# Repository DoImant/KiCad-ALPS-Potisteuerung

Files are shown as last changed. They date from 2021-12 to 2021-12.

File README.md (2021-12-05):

# ALPS potentiometer control

Circuit for controlling an ALPS motor potentiometer with the help of an IR remote\
control. This circuit can be used to control the volume of an amplifier.

## Circuit diagram as PDF file

[Sheet](https://github.com/DoImant/Stuff/blob/main/ALPS-Drehpoti/ALPS-Potisteuerung.pdf)

## The PCB

PCB



## Software

The software for the Atmega88P can be found here: https://github.com/DoImant/ATmega88-ALPS-Motorpoti

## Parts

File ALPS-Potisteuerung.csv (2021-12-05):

Reference | Quantity | Value | Footprint | Datasheet | EAN / GTIN | Hersteller | Distributor | Artikelnummer Distributor
C1 | 1 | 220u | Capacitor_SMD:CP_Elec_6.3x5.8 | ~ | 9900002001580 | Panasonic | Reichelt | EEEFT1C221AP
C2 C3 | 2 | 1uF | Capacitor_SMD:C_1206_3216Metric_Pad1.33x1.80mm_HandSolder | ~
C4 C5 C9 C10 | 4 | 100n | Capacitor_SMD:C_1206_3216Metric_Pad1.33x1.80mm_HandSolder | ~
C6 C7 | 2 | 22p | Capacitor_THT:C_Disc_D3.0mm_W1.6mm_P2.50mm | ~
C8 | 1 | 10n | Capacitor_SMD:C_1206_3216Metric_Pad1.33x1.80mm_HandSolder | ~
D1 | 1 | MBR0520LT | Diode_SMD:D_SOD-123 | http://www.onsemi.com/pub_link/Collateral/MBR0520LT1-D.PDF | 9900002196200 | ON Semiconductor | Reichelt
H1 H2 H3 H4 | 4 | MountingHole | MountingHole:MountingHole_3.2mm_M3_DIN965_Pad | ~
J1 | 1 | Conn_01x02 | TerminalBlock_RND:TerminalBlock_RND_205-00232_1x02_P5.08mm_Horizontal | ~
J2 | 1 | Conn_01x03_Male | Connector_JST:JST_XH_B3B-XH-A_1x03_P2.50mm_Vertical | ~
J3 | 1 | Conn_02x03_Odd_Even | Connector_IDC:IDC-Header_2x03_P2.54mm_Vertical | ~
J4 | 1 | Conn_01x02 | Connector_PinHeader_2.54mm:PinHeader_1x02_P2.54mm_Vertical | ~
J5 | 1 | Conn_01x02 | Connector_JST:JST_XH_B2B-XH-A_1x02_P2.50mm_Vertical | ~
Q1 | 1 | IRLML6402 | Package_TO_SOT_SMD:SOT-23 | https://www.infineon.com/dgdl/irlml6402pbf.pdf?fileId=5546d462533600a401535668d5c2263c | 9900001087431 | Infenion | Reichelt
R1 | 1 | 22k | Resistor_SMD:R_1206_3216Metric_Pad1.30x1.75mm_HandSolder | ~
R2 | 1 | 150 | Resistor_SMD:R_1206_3216Metric_Pad1.30x1.75mm_HandSolder | ~
R3 | 1 | 56k | Resistor_SMD:R_1206_3216Metric_Pad1.30x1.75mm_HandSolder | ~
U1 | 1 | MCP1703A-5002_SOT23 | Package_TO_SOT_SMD:SOT-23 | http://ww1.microchip.com/downloads/en/DeviceDoc/20005122B.pdf | 9900001372926 | Microchip | Reichelt
U2 | 1 | ATmega88PA-PU | Package_DIP:DIP-28_W7.62mm | http://ww1.microchip.com/downloads/en/DeviceDoc/ATmega48PA_88PA_168PA-Data-Sheet-40002011A.pdf | 9900001218354 | Microchip | Reichelt
U3 | 1 | L293D | Package_DIP:DIP-16_W7.62mm | http://www.ti.com/lit/ds/symlink/l293.pdf | 9900000096618 | ST Microeletronics
Y1 | 1 | 8Mhz | Crystal:Crystal_HC49-4H_Vertical | ~

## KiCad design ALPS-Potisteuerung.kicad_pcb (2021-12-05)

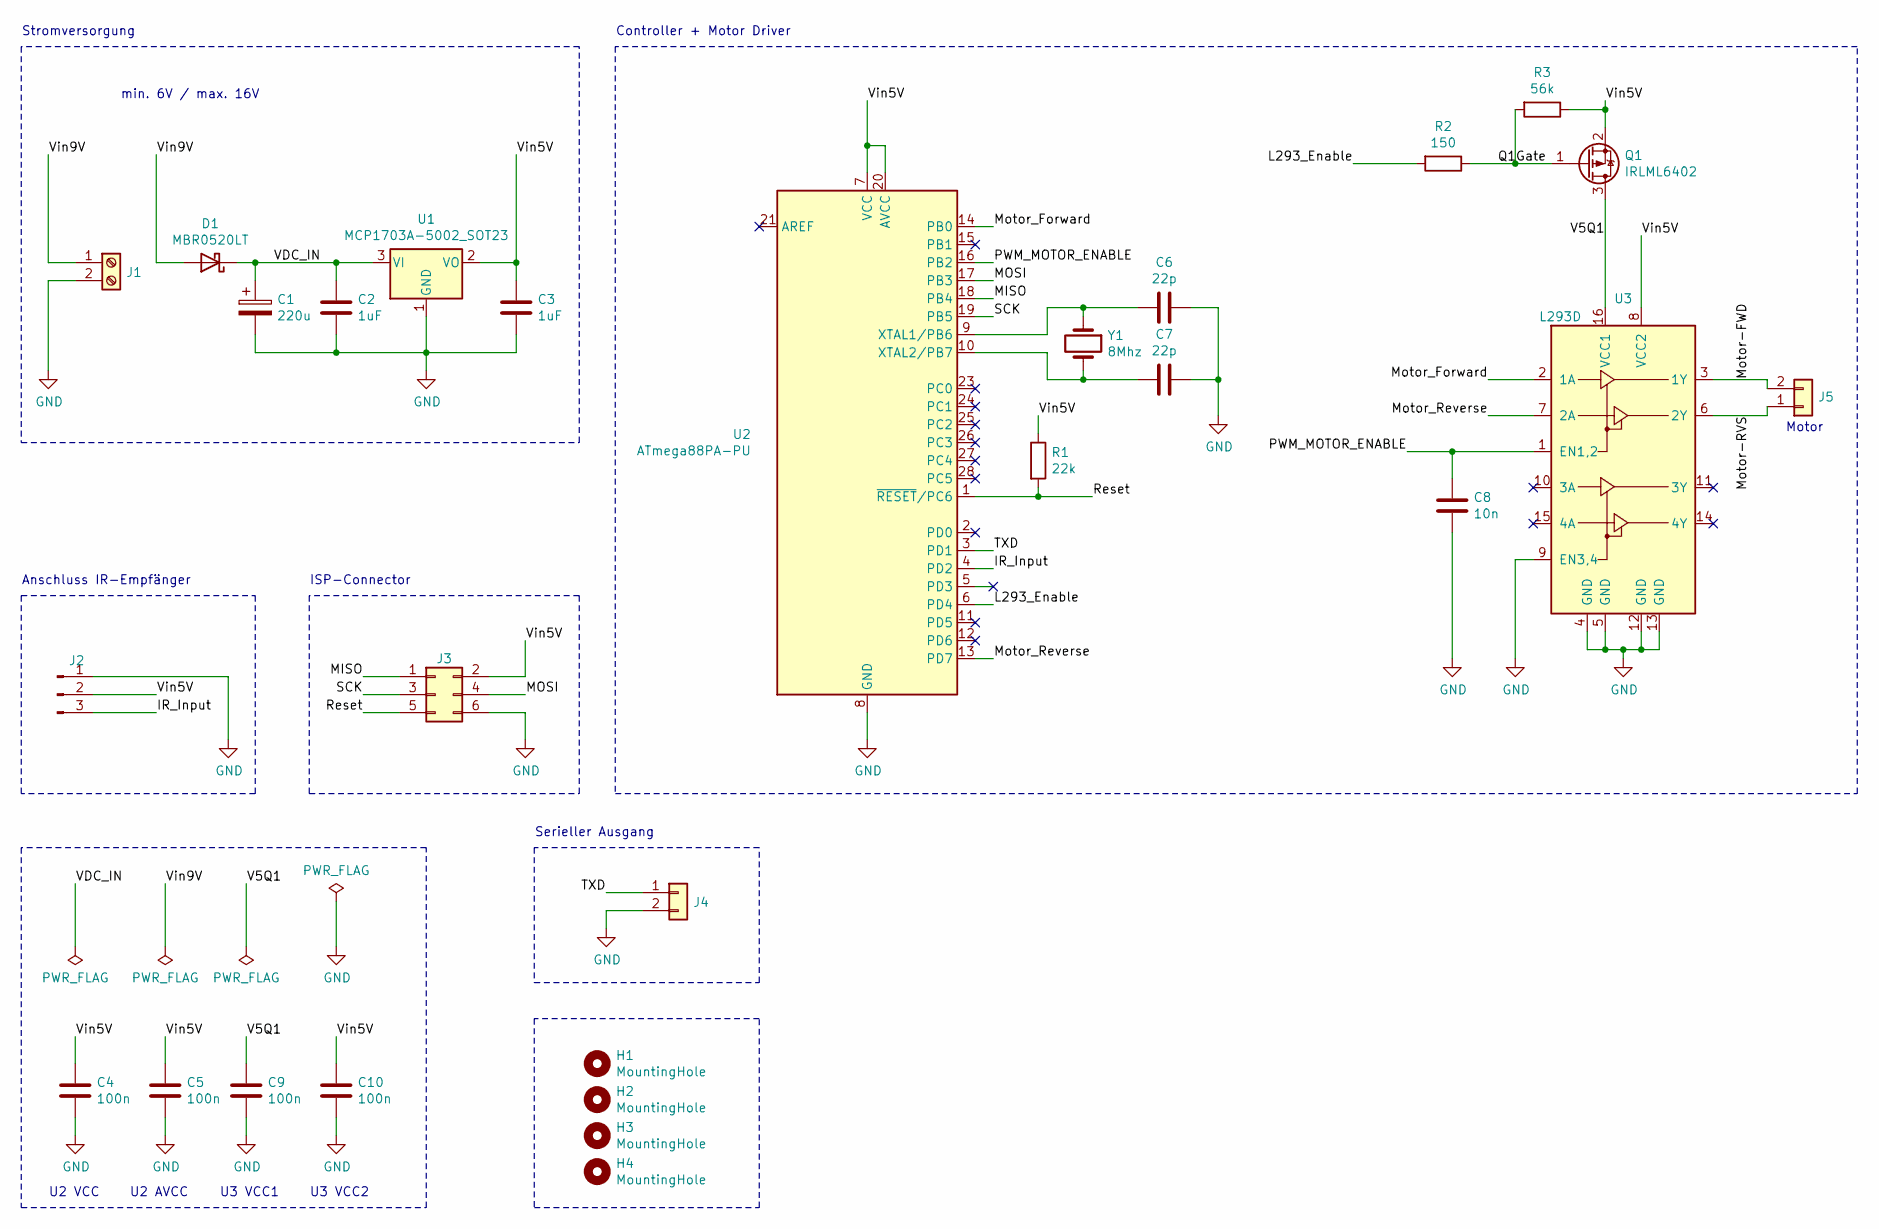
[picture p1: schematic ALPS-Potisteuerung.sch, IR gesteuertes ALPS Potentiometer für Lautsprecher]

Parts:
C1: 220u; CP_Elec_6.3x5.8
C2, C3: 1uF; C_1206_3216Metric_Pad1.33x1.80mm_HandSolder
C4, C5, C9, C10: 100n; C_1206_3216Metric_Pad1.33x1.80mm_HandSolder
C6, C7: 22p; C_Disc_D3.0mm_W1.6mm_P2.50mm
C8: 10n; C_1206_3216Metric_Pad1.33x1.80mm_HandSolder
D1: MBR0520LT; D_SOD-123
H1, H2, H3, H4: MountingHole; MountingHole_3.2mm_M3_DIN965_Pad
J1: Conn_01x02; TerminalBlock_RND_205-00232_1x02_P5.08mm_Horizontal
J2: Conn_01x03_Male; JST_XH_B3B-XH-A_1x03_P2.50mm_Vertical
J3: Conn_02x03_Odd_Even; IDC-Header_2x03_P2.54mm_Vertical
J4: Conn_01x02; PinHeader_1x02_P2.54mm_Vertical
J5: Conn_01x02; JST_XH_B2B-XH-A_1x02_P2.50mm_Vertical
Q1: IRLML6402; SOT-23
R1: 22k; R_1206_3216Metric_Pad1.30x1.75mm_HandSolder
R2: 150; R_1206_3216Metric_Pad1.30x1.75mm_HandSolder
R3: 56k; R_1206_3216Metric_Pad1.30x1.75mm_HandSolder
U1: MCP1703A-5002_SOT23; SOT-23
U2: ATmega88PA-PU; DIP-28_W7.62mm
U3: L293D; DIP-16_W7.62mm
Y1: 8Mhz; Crystal_HC49-4H_Vertical

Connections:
/IR_Input: J2.3, U2.4 (PD2)
/L293_Enable: R2.2, U2.6 (PD4)
/MISO: J3.1, U2.18 (PB4)
/MOSI: J3.4, U2.17 (PB3)
/Motor-FWD: J5.2, U3.3 (1Y)
/Motor-RVS: J5.1, U3.6 (2Y)
/Motor_Forward: U2.14 (PB0), U3.2 (1A)
/Motor_Reverse: U2.13 (PD7), U3.7 (2A)
/PWM_MOTOR_ENABLE: C8.1, U2.16 (PB2), U3.1 (EN1,2)
/Q1Gate: Q1.1 (G), R2.1, R3.2
/Reset: J3.5, R1.2, U2.1 (~RESET~/PC6)
/SCK: J3.3, U2.19 (PB5)
/TXD: J4.1, U2.3 (PD1)
/V5Q1: C9.1, Q1.3 (D), U3.16 (VCC1)
/VDC_IN: C1.1, C2.1, D1.1 (K), U1.3 (VI)
/Vin5V: C3.1, C4.1, C5.1, C10.1, J2.2, J3.2, Q1.2 (S), R1.1, R3.1, U1.2 (VO), U2.7 (VCC), U2.20 (AVCC), U3.8 (VCC2)
/Vin9V: D1.2 (A), J1.1
GND: C1.2, C2.2, C3.2, C4.2, C5.2, C6.1, C7.1, C8.2, C9.2, C10.2, J1.2, J2.1, J3.6, J4.2, U1.1 (GND), U2.8 (GND), U2.22 (GND), U3.4 (GND), U3.5 (GND), U3.9 (EN3,4), U3.12 (GND), U3.13 (GND)
unnamed: C6.2, U2.9 (XTAL1/PB6), Y1.1
unnamed: C7.2, U2.10 (XTAL2/PB7), Y1.2

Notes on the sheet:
Motor
min. 6V / max. 16V
Anschluss IR-Empfänger
Stromversorgung
ISP-Connector
Controller + Motor Driver
Serieller Ausgang
U2 VCC
U2 AVCC
U3 VCC1
U3 VCC2

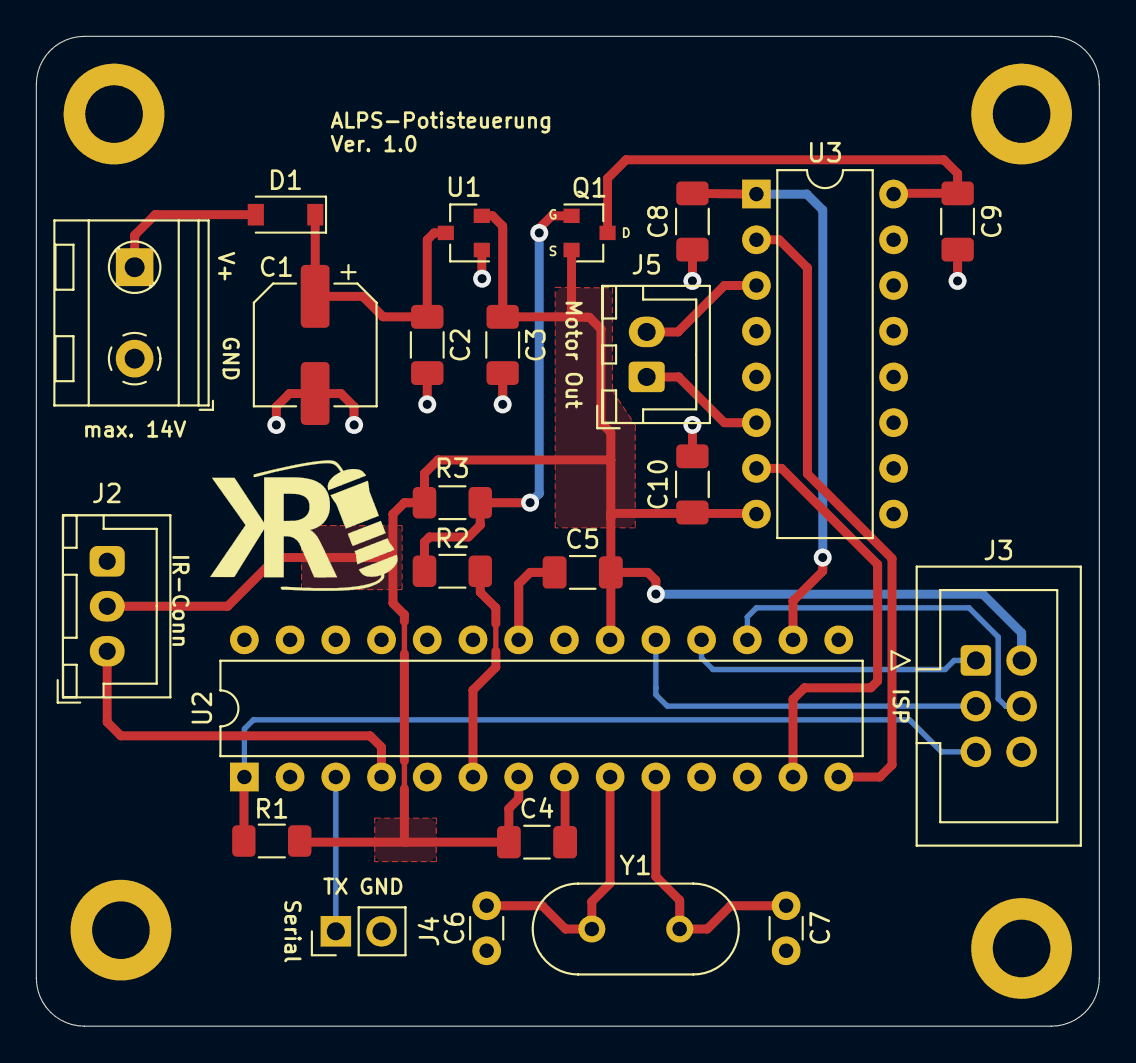
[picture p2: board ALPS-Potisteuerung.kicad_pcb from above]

Board: 2 copper layers, 59.1 x 55.0 mm, 28 parts (0 on the bottom side), 20 nets.
